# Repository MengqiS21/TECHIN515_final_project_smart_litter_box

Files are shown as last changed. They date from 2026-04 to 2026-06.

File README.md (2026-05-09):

# Smart Cat Litter Box — TECHIN 515 Final Project

An IoT-enabled smart litter box that uses a load cell weight sensor to monitor cat usage patterns and track cat weight over time. The system is built around a Seeed Studio XIAO ESP32-S3 microcontroller and an HX711 24-bit ADC for high-precision weight measurement.

---

## Hardware Requirements

| Component | Specification |
|---|---|
| Microcontroller | Seeed Studio XIAO ESP32-S3 |
| ADC Module | HX711 24-Bit Load Cell Amplifier |
| Sensor | Load cell (rated for expected weight range) |
| Cable | USB-C (for programming and serial monitor) |
| Enclosure | 3D-printed base (see `Base.stl`) |

---

## Wiring

### HX711 (load cell amplifier)

| HX711 Pin | XIAO ESP32-S3 Pin | GPIO |
|---|---|---|
| DT (Data) | D3 | GPIO 4 |
| SCK (Clock) | D4 | GPIO 5 |
| VCC | 3.3V | — |
| GND | GND | — |

Connect the load cell's four wires to the HX711 module following the color convention printed on the HX711 board (typically: Red=E+, Black=E−, White=A−, Green=A+).

### PIR motion sensor

Typical 3-pin HC-SR501-style PIR module wiring to the XIAO ESP32-S3:

| PIR Pin | XIAO ESP32-S3 Pin | GPIO |
|---|---|---|
| VCC | **3.3V** | — |
| GND | **GND** | — |
| OUT (digital signal) | **D3** | GPIO 4 |

Power the PIR from **3.3 V** so its output levels are safe for the ESP32 GPIO. Use **`INPUT_PULLUP`** (or an external pull-up per your module datasheet) on the signal pin if your sketch expects an active-low/open-drain output.

On the XIAO ESP32-S3, **D3** corresponds to **GPIO 4** — set `PIR_PIN` (or equivalent) in your sketch to **`4`** when using this wiring. The sample `code/PIR_data_capture.ino` may default to another pin; update it to match your board.

**HX711 + PIR on one board:** One GPIO cannot be both HX711 **DT** and PIR **OUT**. If you keep PIR on **D3**, move HX711 **DT** to another free digital pin and update the DT pin in your weight-reading sketch so both peripherals can run together.

---

## Software Requirements

### 1. Arduino IDE
Download and install **Arduino IDE 2.x** from https://www.arduino.cc/en/software

### 2. ESP32-S3 Board Support
1. Open Arduino IDE → **File → Preferences**
2. In *Additional boards manager URLs*, add:
   ```
   https://raw.githubusercontent.com/espressif/arduino-esp32/gh-pages/package_esp32_index.json
   ```
3. Go to **Tools → Board → Boards Manager**, search for `esp32`, and install **esp32 by Espressif Systems** (version 2.x or later)

### 3. Required Library
Install via **Tools → Manage Libraries**:

| Library | Author | Version |
|---|---|---|
| `HX711_ADC` | Olav Kallhovd | Latest |

Search for `HX711_ADC` and click **Install**.

> See `code/libraries.txt` for a machine-readable list of required libraries.

---

## Board Configuration in Arduino IDE

Go to **Tools** and set:

| Setting | Value |
|---|---|
| Board | XIAO_ESP32S3 |
| Port | (select the COM/tty port that appears when you plug in the board) |
| USB CDC On Boot | Enabled |
| Upload Speed | 921600 |

---

## Code Structure

```
code/
├── Read_ESP32S3_NoCalib(1).ino   # Step 1 — Connection test (raw ADC, no calibration)
├── Calibration_ESP32S3.ino       # Step 2 — Sensor calibration, saves value to EEPROM
└── Read_ESP32S3.ino              # Step 3 — Production use with calibration applied
```

> **Important (Arduino IDE requirement):** When you open an `.ino` file that is not inside a folder with the same name, Arduino IDE will prompt you to create a matching folder and move the file. Click **OK** to accept — this is required behavior and does not affect the code.

---

## Running the Code — Step by Step

### Step 1: Verify Circuit Connection (No Calibration)

Use this sketch first to confirm that the load cell and HX711 are wired correctly.

1. Open `Read_ESP32S3_NoCalib(1).ino` in Arduino IDE
2. Select the correct board and port (see Board Configuration above)
3. Click **Upload**
4. Open **Tools → Serial Monitor**, set baud rate to **115200**
5. You should see raw ADC values printing continuously
6. Place a weight on the load cell — the values should change noticeably
7. If values change, wiring is correct. Proceed to Step 2.

**Serial commands:**
- `t` — Tare (zero) the sensor

---

### Step 2: Calibrate the Sensor

Run this sketch once to calculate and save a calibration factor to EEPROM.

1. Open `Calibration_ESP32S3.ino` in Arduino IDE
2. Upload to the XIAO ESP32-S3
3. Open **Serial Monitor** at **115200 baud**
4. Follow the on-screen prompts:
   - Remove all weight from the load cell
   - Send `t` to tare (zero) the sensor
   - Place a **known-weight object** (e.g., 100.0 g) on the load cell
   - Type the exact weight value (e.g., `100.0`) in the Serial Monitor and press Enter
   - When asked, send `y` to save the calibration value to EEPROM
5. Note the printed calibration value — it is also saved automatically to EEPROM address 0

**Serial commands during calibration:**
- `t` — Tare
- `r` — Restart calibration
- `c` — Manually enter and save a new calibration factor

---

### Step 3: Read Actual Weight

After calibration, use this sketch for normal operation.

1. Open `Read_ESP32S3.ino` in Arduino IDE
2. Upload to the XIAO ESP32-S3
3. Open **Serial Monitor** at **115200 baud**
4. The sketch automatically reads the calibration factor from EEPROM and prints the calibration value used
5. Weight readings (in grams, relative to calibration) are printed every **1 second**

**Serial commands:**
- `t` — Tare (re-zero the sensor)

> If weight readings appear as large negative numbers, uncomment `LoadCell.setReverseOutput();` in the sketch (line 36) and re-upload.

---

## Troubleshooting

| Symptom | Likely Cause | Fix |
|---|---|-----|
| Timeout error on startup | Incorrect wiring or wrong GPIO pins | Double-check DT→GPIO4, SCK→GPIO5 |
| No serial output | USB CDC not enabled or wrong port | Enable USB CDC On Boot in board settings |
| Values don't change when weight added | Loose connection or broken load cell | Re-seat all connections |
| Calibration value reads as `nan` or `0` | EEPROM not yet written | Run calibration sketch first |
| Weight reads negative | Load cell wired in reverse | Uncomment `setReverseOutput()` |

---

## Repository Contents

| File | Description |
|---|---|
| `code/Calibration_ESP32S3.ino` | Calibration sketch for ESP32-S3 |
| `code/Read_ESP32S3.ino` | Production weight reading sketch |
| `code/Read_ESP32S3_NoCalib(1).ino` | Connection test sketch (raw ADC) |
| `code/libraries.txt` | Required Arduino libraries |
| `Base.stl` | 3D model of the litter box base |
| `TECHIN515_Budget.pdf` | Project budget breakdown |
| `Prototype1_HX711_Weight_Sensor_Test_Report.pdf` | Milestone 1 test report |
| `Smart_Cat_Litter_Box_Milestone1(3).pptx` | Project presentation slides |

---

## Authors

Xin Luo, Yuna Xiong, Mengqi Shi — Spring 2026

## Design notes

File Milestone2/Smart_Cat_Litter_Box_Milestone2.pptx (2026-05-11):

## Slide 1

MILESTONE 2

TEAM PROJECT

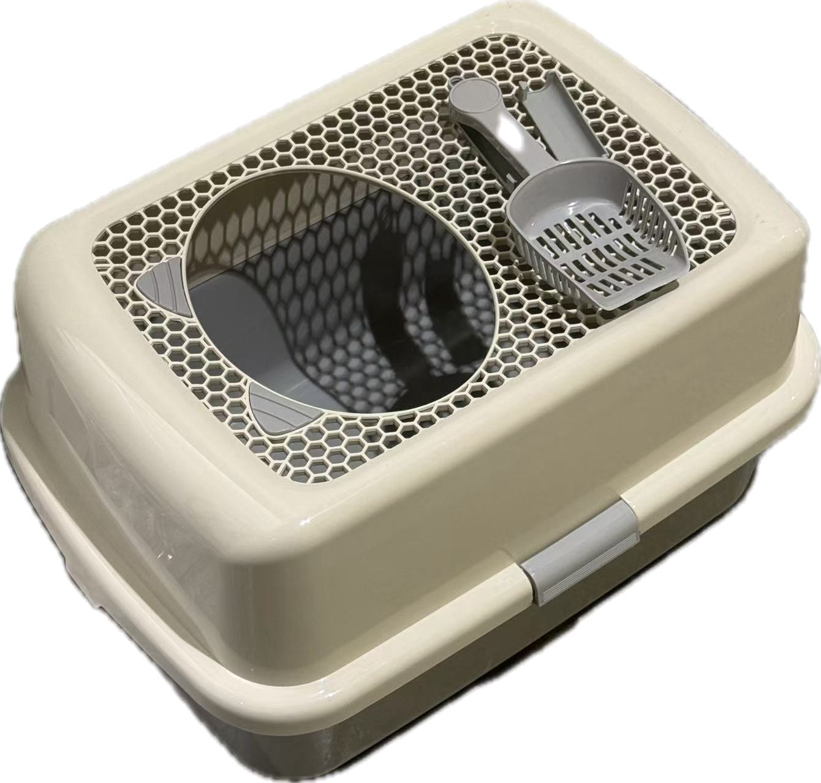
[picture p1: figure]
图片 1

Smart Cat Litter

Box Monitor

Passive health tracking for cats through visit, weight, and pattern monitoring.

TEAM

Mengqi Shi Yuna Xiong Xin Luo

TEAM

Team SmartLitterBox

GITHUB

https://github.com/MengqiS21/TECHIN515_final_project_smart_litter_box

Smart Cat Litter Box Monitor | Milestone 1

1 / 8

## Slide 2

01 PROBLEM

The Problem & Who It Affects

THE PROBLEM

Cat owners have no easy way to detect early signs of health issues from litter box behavior.

BY THE NUMBERS

64.5%

of cats with urinary tract issues show no obvious symptoms until the condition becomes serious

INTENDED USER GROUP

Cats often hide symptoms of illness such as urinary blockages or weight loss. Subtle changes in litter box visit frequency, duration, and body weight are hard to notice without consistent tracking. By the time owners spot a problem, the condition may already be serious.

Cat owners who want passive, automatic monitoring of their cat's health through litter box usage patterns, without relying on manual observation or frequent vet visits.

Smart Cat Litter Box Monitor | Milestone 1

2 / 8

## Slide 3

02 SOLUTION

Our Solution & Key Features

IN ONE SENTENCE

KEY FEATURES

Visit Detection

PIR sensor captures entry and exit automatically for every visit.

A litter box mounted edge device that uses a PIR sensor and load cell to track each visit's duration and weight, runs anomaly detection against a personalized baseline on the ESP32S3, and syncs logs to a cloud dashboard for long term trend viewing.

HARDWARE STACK

XIAO ESP32S3 | Load cell + HX711 | PIR sensor

01

02

Weight Tracking

Load cell measures cat weight per visit and tracks long term trends.

03

On Device Anomaly

Rule based detector compares each visit to a personalized 7 day baseline.

04

Cloud Trends

MQTT upload to a dashboard so owners can view history and alerts.

Smart Cat Litter Box Monitor | Milestone 1

3 / 8

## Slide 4

03 ARCHITECTURE

Updated System Architecture

Proven

In progress

Blocked

NODE A: Sensor Unit

PIR Motion
Sensor

Signal
Processing

Cloud Upload
(MQTT)

ESP32S3
Node A

Frontend
UI

Anomaly
Detection

Cloud
Dashboard

ESP NOW

feedback: updated baseline

NODE B: Weight Unit

Load Cell
+ HX711

ESP32S3
Node B

Two ESP32S3 nodes communicate via ESP NOW. Solid lines mark tested interfaces. Dashed lines mark interfaces not yet verified.

Smart Cat Litter Box Monitor | Milestone 2

4 / 8

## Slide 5

04 TRADE OFF

Trade Off Analysis

Sweeping system parameters to evaluate impact on performance metrics.

Stabilization Window

PARAMETER

HX711 stabilization time controls how long the system waits after detecting a visit before recording a stable weight reading. Tested at 1s, 3s, 5s, and 7s windows to evaluate the trade off between reading accuracy and response speed.

RESULT

At 1s, readings showed high variance due to the cat's movement on the load cell. At 3s, standard deviation dropped significantly but occasional spikes remained. At 5s, mean error reached 0.11 g with 0.23 g standard deviation, providing stable readings with acceptable latency. At 7s, accuracy improved only marginally while adding unnecessary delay.

Communication Protocol

PARAMETER

Evaluated three options for communication between the sensor node (ESP32S3 + PIR) and the weight node (ESP32S3 + HX711): ESP NOW, Wi Fi, and BLE. Compared on latency, power consumption, and ease of implementation.

RESULT

Wi Fi offers high throughput but requires a router and draws significantly more power, which is not ideal for a battery powered device. BLE is low power but introduces pairing complexity and higher latency for real time data transfer. ESP NOW enables direct peer to peer communication between two ESP32S3 boards with no router dependency, sub 10 ms latency, and minimal power overhead.

01

02

Smart Cat Litter Box Monitor | Milestone 2

5 / 8

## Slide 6

05 VALIDATION

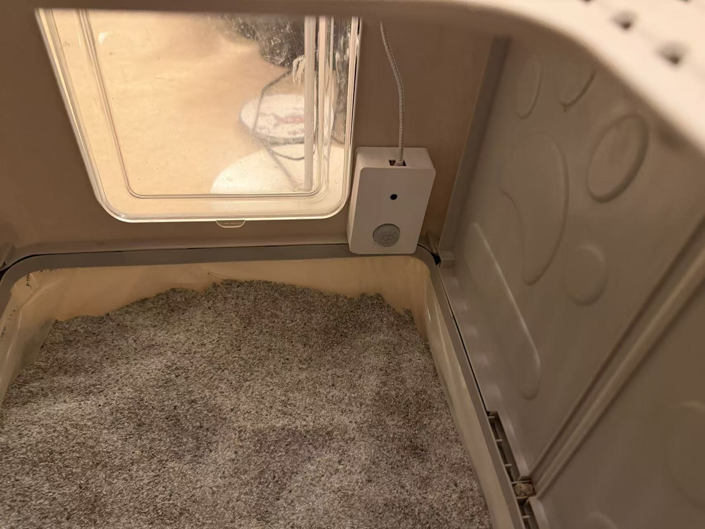
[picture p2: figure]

Validation: Data Collection & Integration

Systematic validation of sensor integration, data pipeline, and model readiness.

Data Labeling

Collected images manually labeled into three categories: Cat A, Cat B, and Empty litter box.

Feature Extraction

Image features extracted through the Edge Impulse DSP pipeline for input into the classification model.

Model Training

Classification model trained to identify which cat is visiting

Sensor Data Collection

PIR sensor detects motion and triggers the ESP32S3 camera module to capture an image.

1

▶

2

▶

3

▶

4

Data Collected

600 images total across three categories (Cat A, Cat B, Empty). All captured via PIR triggered camera on the ESP32S3. Insert sample images from each category and a photo of the hardware setup.

Quantitative Results

HX711 weight sensor validated with mean error 0.11 g and std dev 0.23 g over 20 trials. Image classification accuracy 89.8% on test set.

Model / Next Steps

lassification model can distinguish between Cat A, Cat B, and Empty. Next step is integrating the classifier output with weight and visit duration data to build the full anomaly detection pipeline. Cloud upload and dashboard display to follow.

Smart Cat Litter Box Monitor | Milestone 2

6 / 8

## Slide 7

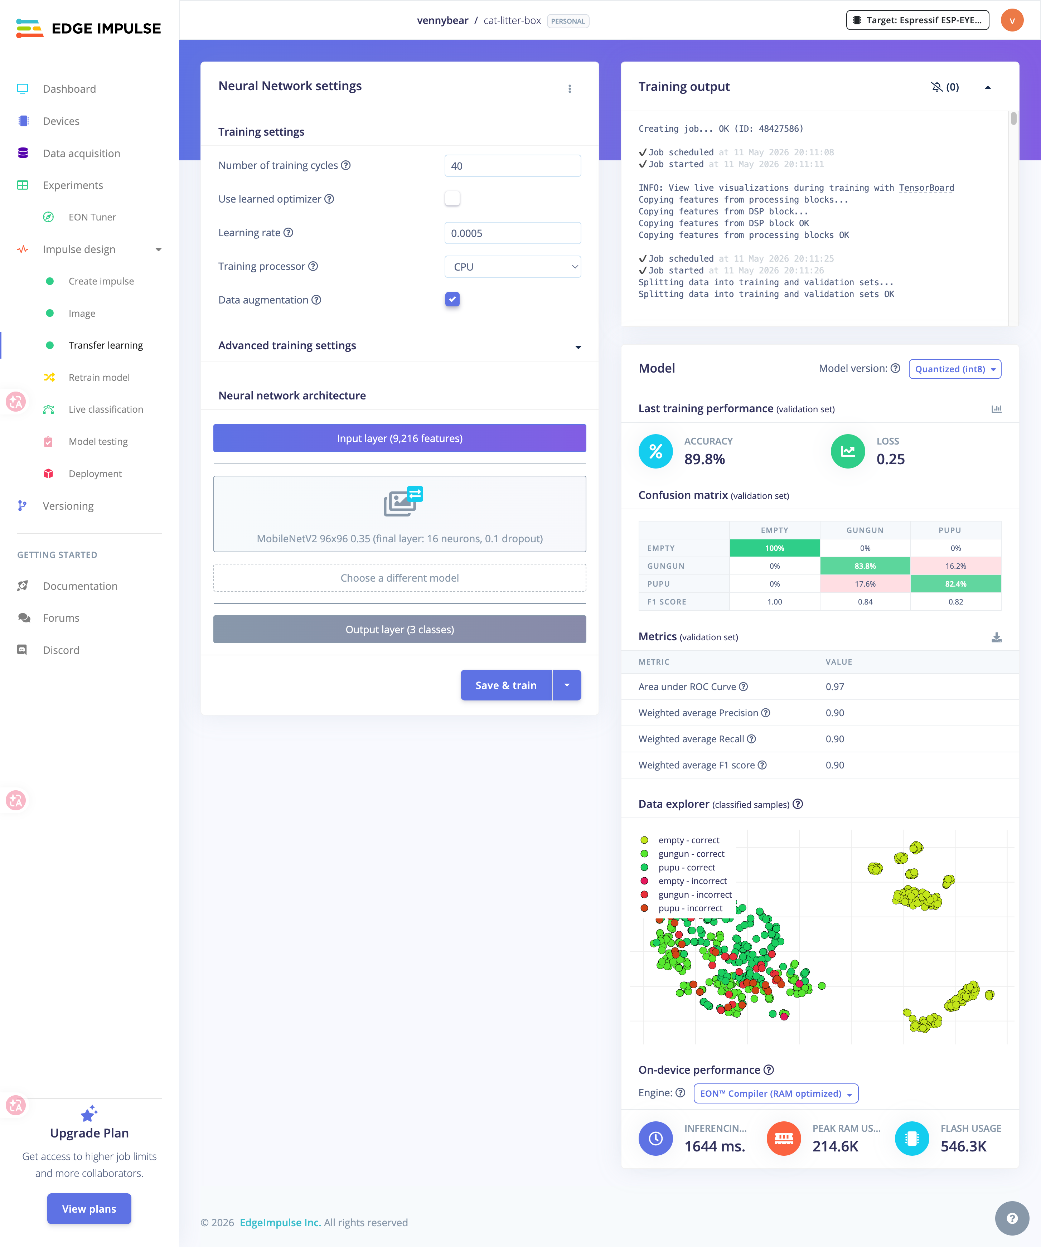
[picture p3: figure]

Smart Cat Litter Box Monitor | Milestone 2

7/ 8

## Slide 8

05 BUDGET

Budget Update

TOTAL BUDGET

$ 350

PURCHASES TO DATE

SPENT SO FAR

$ 57.38

REMAINING

$ 292.62

Item | Qty | Unit Cost | Total
[LiPo battery] | [1] | [$ 5.83] | [$ 5.83]
[LiPo charger module (TP4057, 5pcs)] | [1] | [$ 7.56] | [$ 7.56]
[Cat litter box(Smart Paws,enclosed)] | [1] | [$ 43.99] | [$ 43.99]
[XIAO ESP32S3] | [2] | [$ 0.00] | [$ 0.00]
[Load cell + HX711] | [1] | [$ 0.00] | [$ 0.00]
[PIR motion sensor] | [1] | [$ 0.00] | [$ 0.00]

Smart Cat Litter Box Monitor | Milestone 1

8 / 8

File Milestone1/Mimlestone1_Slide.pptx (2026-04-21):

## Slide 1

MILESTONE 1

TEAM PROJECT

图片 1

Smart Cat Litter

Box Monitor

Passive health tracking for cats through visit, weight, and pattern monitoring.

TEAM

Mengqi Shi Yuna Xiong Xin Luo

TEAM

Team SmartLitterBox

GITHUB

https://github.com/MengqiS21/TECHIN515_final_project_smart_litter_box

Smart Cat Litter Box Monitor | Milestone 1

1 / 6

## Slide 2

01 PROBLEM

The Problem & Who It Affects

THE PROBLEM

Cat owners have no easy way to detect early signs of health issues from litter box behavior.

BY THE NUMBERS

64.5%

of cats with urinary tract issues show no obvious symptoms until the condition becomes serious

INTENDED USER GROUP

Cats often hide symptoms of illness such as urinary blockages or weight loss. Subtle changes in litter box visit frequency, duration, and body weight are hard to notice without consistent tracking. By the time owners spot a problem, the condition may already be serious.

Cat owners who want passive, automatic monitoring of their cat's health through litter box usage patterns, without relying on manual observation or frequent vet visits.

Smart Cat Litter Box Monitor | Milestone 1

2 / 6

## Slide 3

02 SOLUTION

Our Solution & Key Features

IN ONE SENTENCE

KEY FEATURES

Visit Detection

PIR sensor captures entry and exit automatically for every visit.

A litter box mounted edge device that uses a PIR sensor and load cell to track each visit's duration and weight, runs anomaly detection against a personalized baseline on the ESP32S3, and syncs logs to a cloud dashboard for long term trend viewing.

HARDWARE STACK

XIAO ESP32S3 | Load cell + HX711 | PIR sensor

01

02

Weight Tracking

Load cell measures cat weight per visit and tracks long term trends.

03

On Device Anomaly

Rule based detector compares each visit to a personalized 7 day baseline.

04

Cloud Trends

MQTT upload to a dashboard so owners can view history and alerts.

Smart Cat Litter Box Monitor | Milestone 1

3 / 6

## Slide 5

03 ARCHITECTURE

Updated System Architecture

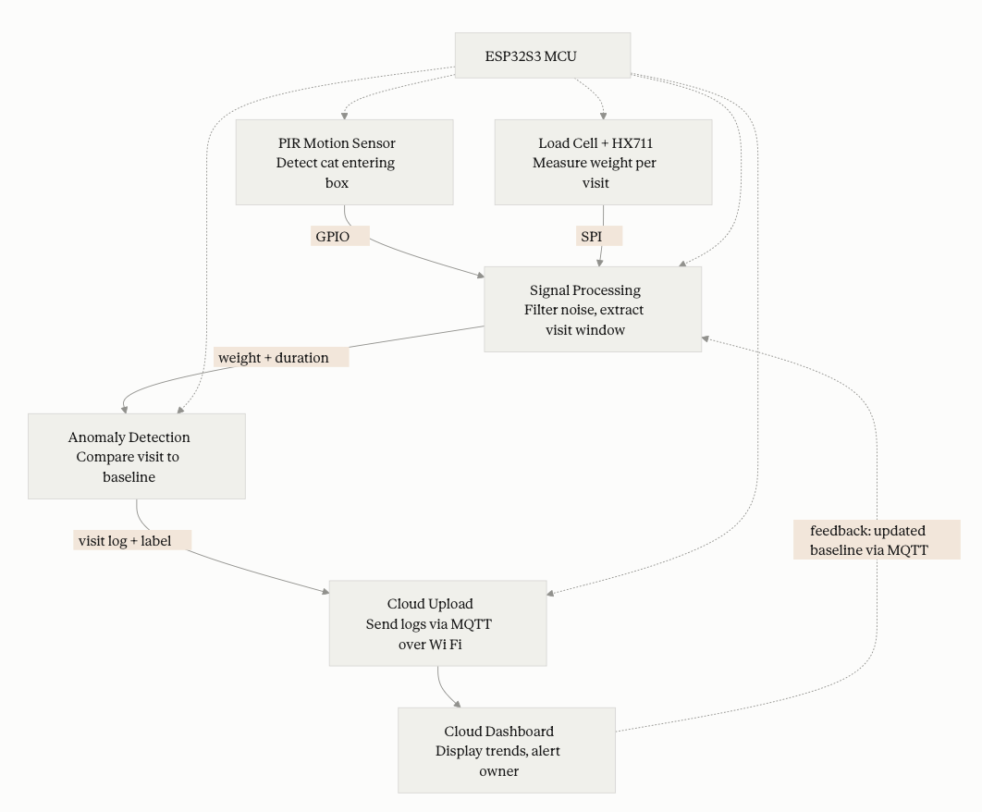
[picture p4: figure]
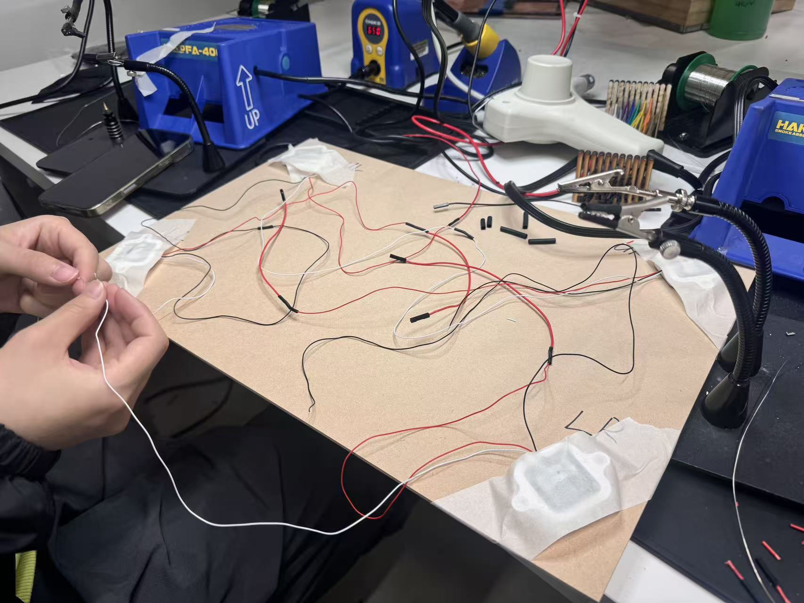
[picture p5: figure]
图片 1
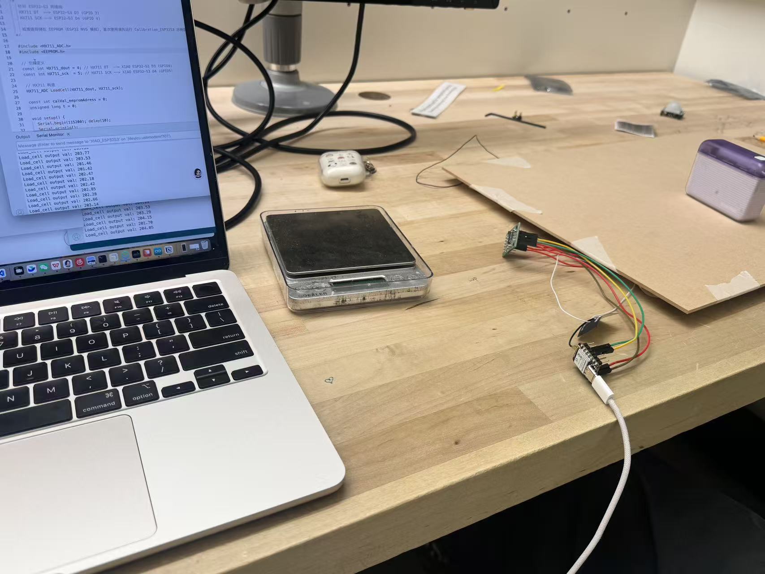
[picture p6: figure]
图片 2

Solid lines mark tested interfaces. Dashed lines mark interfaces not yet verified. Update block status as components move from in progress to proven.

Smart Cat Litter Box Monitor | Milestone 1

4 / 6

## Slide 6

04 VALIDATION

Component Validation & Results

Each component validated with a quantitative test. Evidence: photos, plots, and commits.

YUNA XIONG

Sensor Hardware

METHOD

Connected the HX711 load cell to the XIAO ESP32S3 and placed a 201.56 g reference weight 20 times. Each reading was recorded after a 5000 ms stabilization window at 1000 ms intervals.

RESULT

Mean error 0.11 g, standard deviation 0.23 g. GO verdict, well within the 10 g accuracy threshold.

MENGQI SHI

Signal Stability

METHOD

Analyzed the 20 trial weight readings from the HX711 sensor to evaluate signal noise and reading consistency. Computed error distribution, peak to peak range, and standard deviation across all trials.

RESULT

Peak to peak error range 0.72 g, max error 0.43 g, min error 0.29 g. Signal stable enough to serve as input for the anomaly detection pipeline.

XIN LUO

Data Logging and Transmission

METHOD

Developed the ESP32S3 firmware (Read_ESP32S3.ino) to read and log weight data via serial output. Verified that all 20 readings were captured without data loss at 1000 ms intervals over the test session.

RESULT

20 out of 20 readings successfully captured with zero dropped samples. Firmware logging validated for future MQTT cloud upload integration.

01

02

03

Smart Cat Litter Box Monitor | Milestone 1

5 / 6

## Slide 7

05 BUDGET

Budget Update

TOTAL BUDGET

$ 350

PURCHASES TO DATE

SPENT SO FAR

$ 57.38

REMAINING

$ 292.62

Item | Qty | Unit Cost | Total
[LiPo battery] | [1] | [$ 5.83] | [$ 5.83]
[LiPo charger module (TP4057, 5pcs)] | [1] | [$ 7.56] | [$ 7.56]
[Cat litter box(Smart Paws,enclosed)] | [1] | [$ 43.99] | [$ 43.99]
[XIAO ESP32S3] | [2] | [$ 0.00] | [$ 0.00]
[Load cell + HX711] | [1] | [$ 0.00] | [$ 0.00]
[PIR motion sensor] | [1] | [$ 0.00] | [$ 0.00]

Smart Cat Litter Box Monitor | Milestone 1

6 / 6

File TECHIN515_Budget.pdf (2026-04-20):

## Smart Cat Litter Box Monitor — Team Budget

TECHIN 515 Spring 2026 · Mengqi Shi | Yuna Xiong | Xin Luo · Team Budget: $350.00 · Updated 2026-04-19

### Hardware

Item | Spec / Source | Qty | Unit ($) | Total ($) | Status
XIAO ESP32S3 | Maker Space | 2 | — | 0.00 | MAKER SPACE
Load cell, 4-bar | Maker Space | 1 | — | 0.00 | MAKER SPACE
HX711 amplifier module | Maker Space | 1 | — | 0.00 | MAKER SPACE
PIR motion sensor | Maker Space | 1 | — | 0.00 | MAKER SPACE
LiPo battery, 3.7 V 500 mAh | Jameco / Amazon | 1 | 5.83 | 5.83 | PURCHASED
LiPo charger module (TP4057, 5pcs) | HiLetgo / Amazon | 1 pk | 7.56 | 7.56 | PURCHASED
Resistors / capacitors / headers | Maker Space | — | — | 0.00 | MAKER SPACE
Jumper wires & breadboard | Maker Space | 1 set | — | 0.00 | MAKER SPACE
Cat litter box (Smart Paws, enclosed) | Amazon | 1 | 43.99 | 43.99 | PURCHASED

### PCB & Fabrication

### Cloud & Software

Item | Details | Cost ($)
MQTT broker (HiveMQ Cloud) | Free tier — up to 10 connections | 0.00
Edge Impulse | Free tier | 0.00
Estimated Total Spend | $57.38
Team Budget | $350.00
Remaining (contingency) | $292.62

* ESP32S3, load cell, HX711, PIR, jumper wires, resistors/caps sourced from Maker Space at no cost. PCB fabrication sponsored by school. Purchased Apr 17: LiPo battery $5.83, TP4057 charger 5-pack $7.56, cat litter box $43.99. Remaining $292.62 reserved for high-fidelity enclosure fabrication and any additional components.

2026/4/19 14:25 | TECHIN 515 — Budget
file:///Users/yuna/Desktop/515 Lab2/group project/CFO/budget.html | 1/2

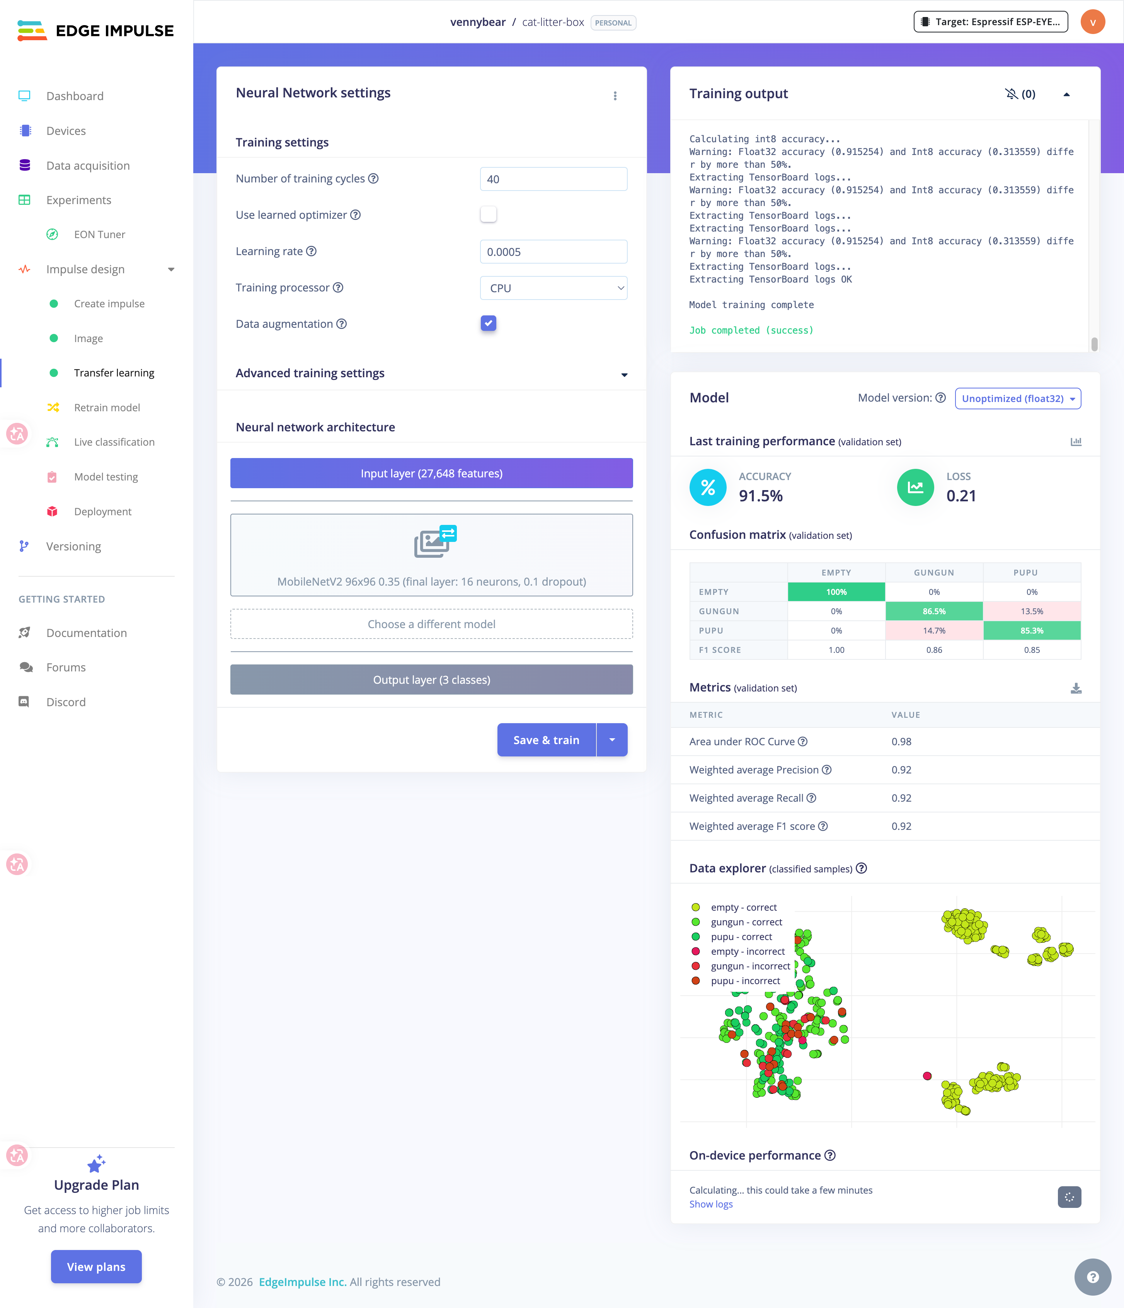
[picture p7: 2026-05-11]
ML screenshot/2round-RGB/Float32 accuracy.png

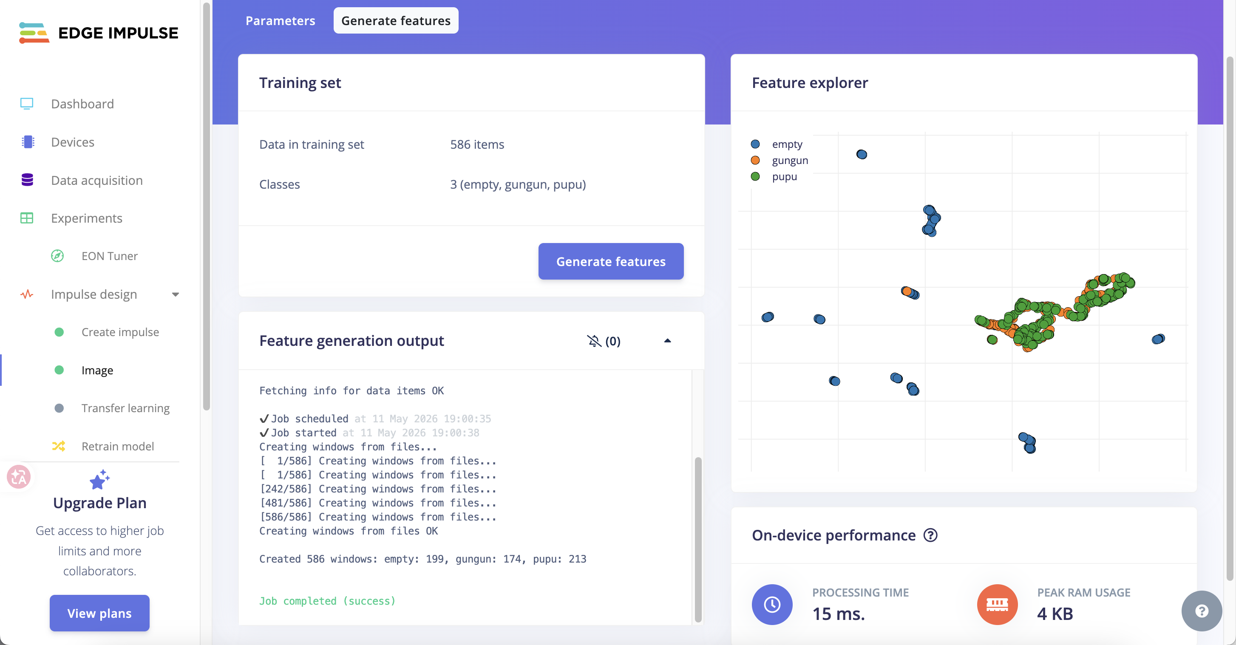
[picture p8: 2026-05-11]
ML screenshot/1-img feature.png

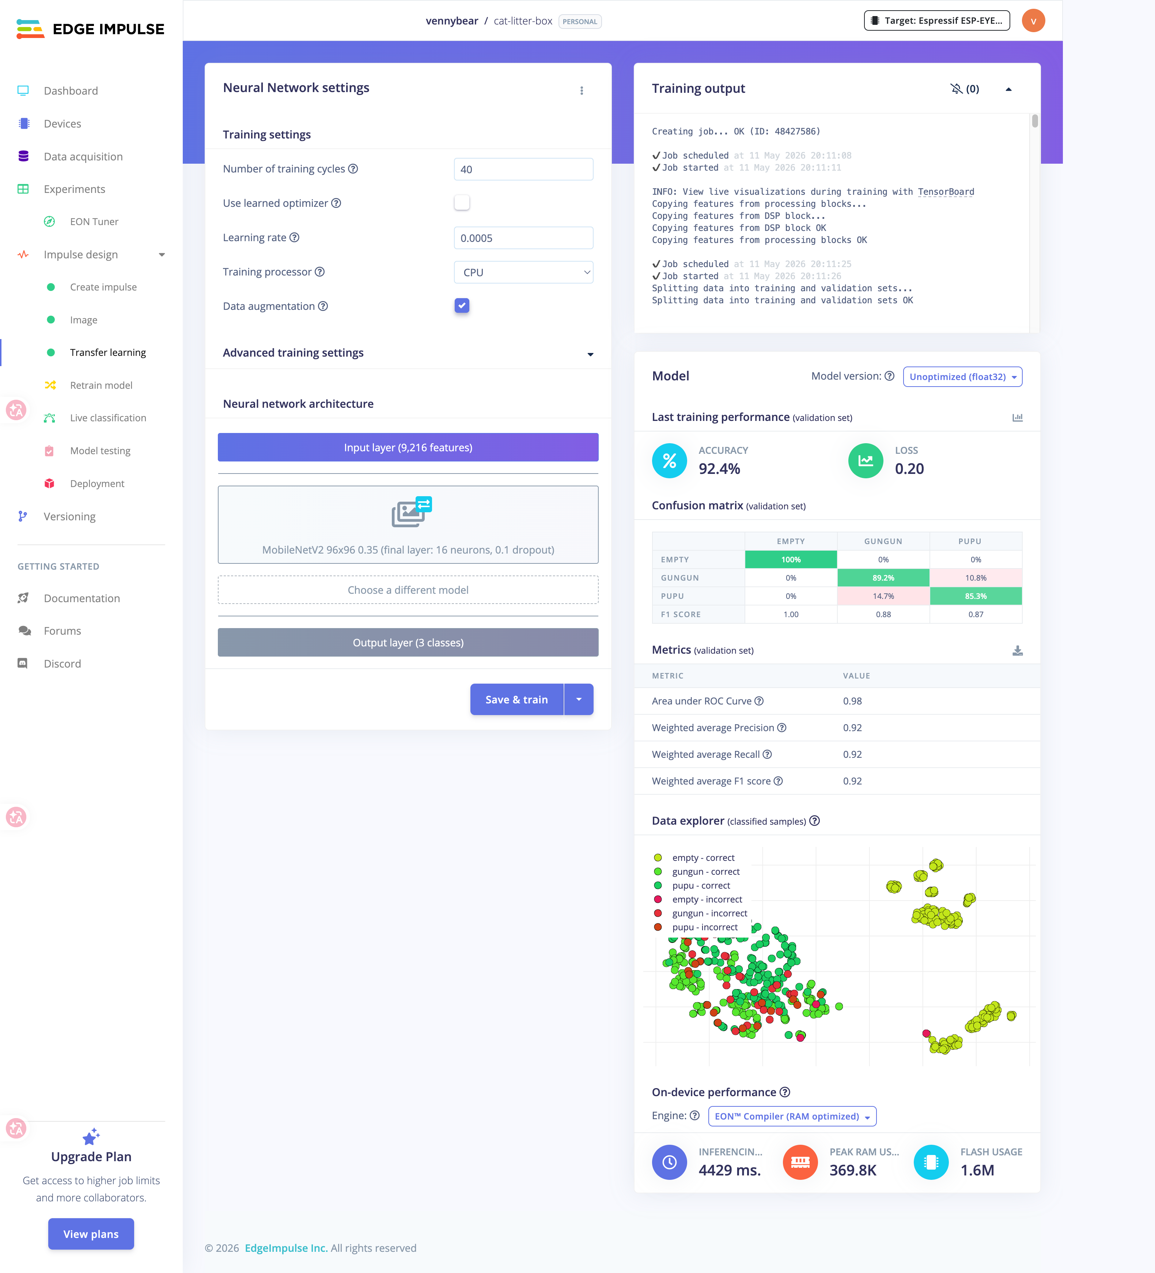
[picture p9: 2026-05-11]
ML screenshot/round3-grayscale/float32.png

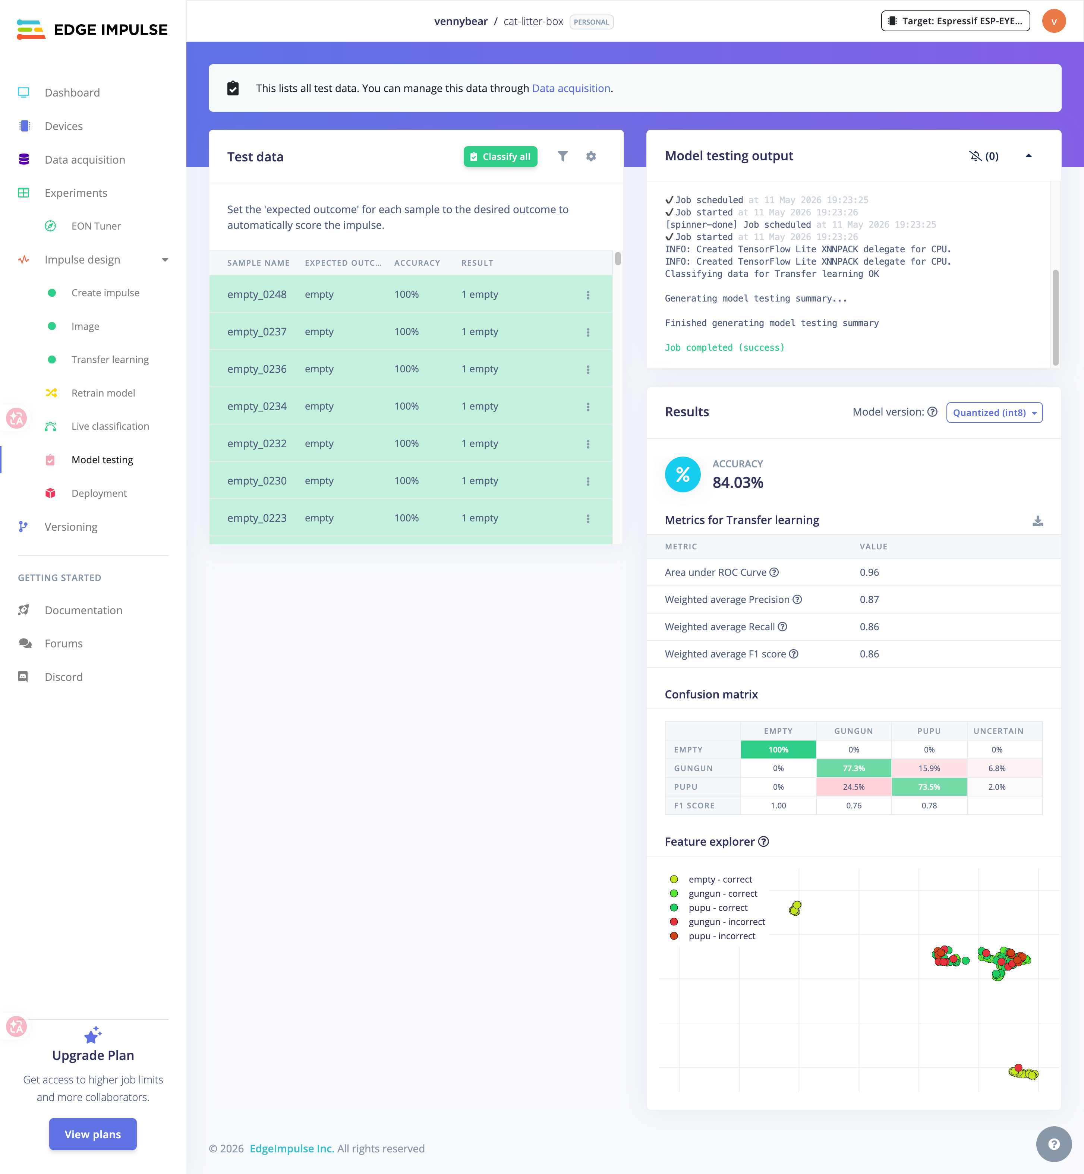
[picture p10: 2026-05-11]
ML screenshot/5-accuracy int8.png

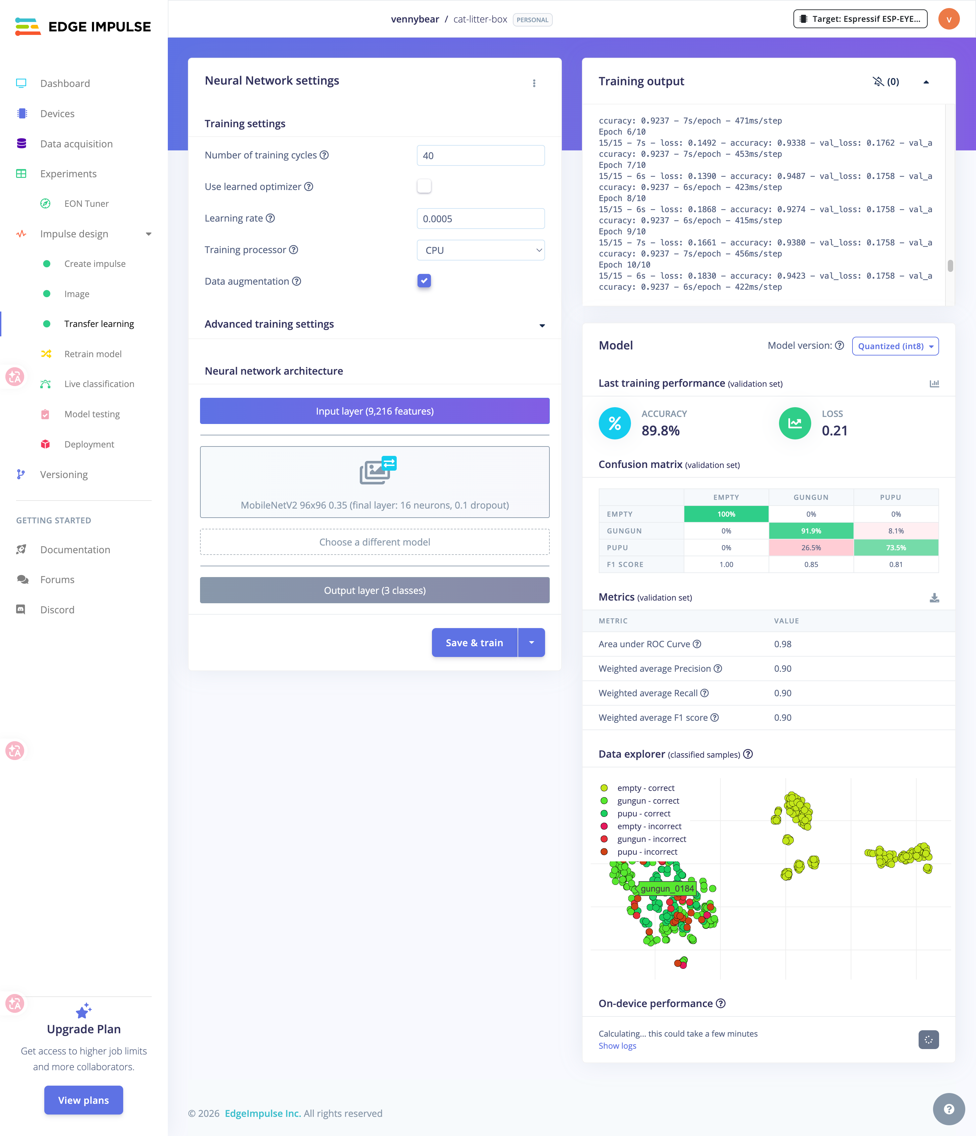
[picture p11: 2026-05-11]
ML screenshot/3-int8.png

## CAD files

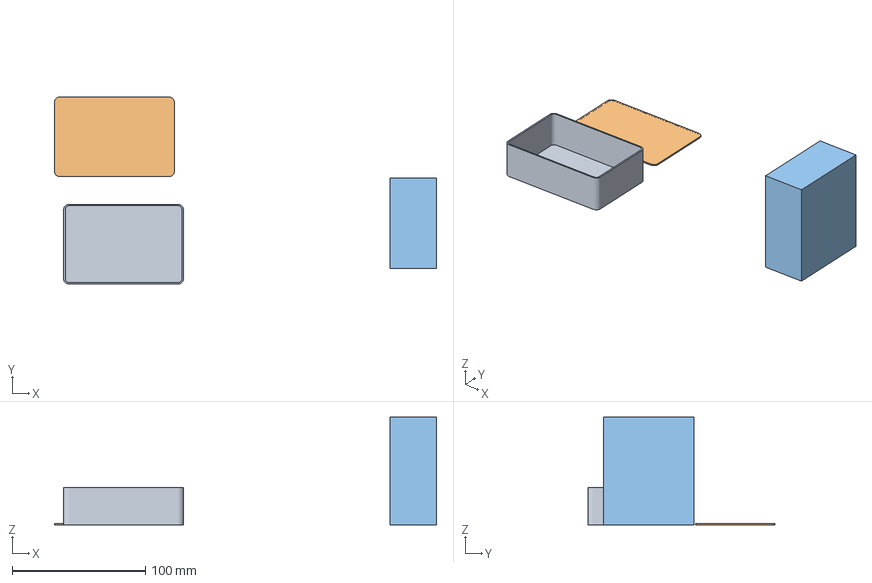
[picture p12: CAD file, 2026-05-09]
enclosure_design/simple_box_generator(1).3mf
287.0 x 140.7 x 81.0 mm
simple_box_generator.stl
simple_box_generator.stl_B

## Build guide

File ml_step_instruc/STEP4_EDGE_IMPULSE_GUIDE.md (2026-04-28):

# Step 4: Edge Impulse 模型训练完整指南
## 用 Edge Impulse 训练猫咪识别模型并部署到 ESP32S3 Sense

---

## 前提条件

在开始之前，你需要：
- 完成 Step 2-3，SD 卡里有标注好的两个文件夹：`cat_a/`（150+ 张）和 `cat_b/`（150+ 张）
- 一台能上网的电脑
- 一个 Edge Impulse 免费账号

---

## Part 1：注册 Edge Impulse 并创建项目

1. 打开 https://studio.edgeimpulse.com/
2. 点击 **Sign up**，用邮箱注册一个免费账号（用学校邮箱 .edu 也可以）
3. 登录后，点击右上角 **Create new project**
4. 项目名称填：`Cat-Identifier-LitterBox`（或任意你喜欢的名字）
5. 选择 **Images** 作为项目类型
6. 点击 **Create**

---

## Part 2：上传照片数据

1. 进入项目后，点击左侧菜单栏的 **Data acquisition**
2. 点击上方的 **Add data** → **Upload data**
3. 上传方式选择 **Select a folder**

### 上传 Cat A 的照片：
- 选择你电脑上的 `cat_a/` 文件夹
- **Label** 填：`cat_a`
- **Upload into category** 选：**Automatically split between training and testing**（Edge Impulse 会自动按 80/20 分成训练集和测试集）
- 点击 **Upload**，等待所有照片上传完成

### 上传 Cat B 的照片：
- 重复上面的步骤，选择 `cat_b/` 文件夹
- **Label** 填：`cat_b`
- 同样选 **Automatically split**
- 点击 **Upload**

### 检查数据：
- 上传完成后，在 **Data acquisition** 页面可以看到所有样本
- 点击顶部的 **Training data** 和 **Test data** 标签切换查看
- 确认两个类别的数量大致平衡（差距不超过 2:1）
- 随机点开几张确认标签正确、照片清晰

---

## Part 3：设计 Impulse（数据处理 Pipeline）

这一步是定义数据从输入到输出的流程。

1. 点击左侧菜单的 **Create impulse**（也叫 Impulse design）
2. 你会看到一个 pipeline 配置界面，按以下方式设置：

### Image data（输入块）：
- **Image width**: `96`
- **Image height**: `96`
- **Resize mode**: `Fit shortest axis`（保持比例缩放后裁剪为正方形）

### 添加 Processing block：
- 点击 **Add a processing block**
- 选择 **Image**（这个块会把原始图片转成模型需要的格式）

### 添加 Learning block：
- 点击 **Add a learning block**
- 选择 **Transfer Learning (Images)**（这就是 MobileNetV2 方案）
- 注意：不要选 "Classification" 里的普通 NN，Transfer Learning 效果好得多

3. 点击 **Save Impulse**

---

## Part 4：配置图像处理参数

1. 点击左侧菜单的 **Image**（在 Impulse design 下面）
2. **Color depth** 选择：**RGB**（猫的毛色是重要特征，保留颜色信息）
3. 点击 **Save parameters**
4. 点击 **Generate features**

这一步会处理你所有的训练图片，生成特征向量。处理完后你会看到一个 2D 可视化图（Feature explorer），如果两只猫的数据点在图上能明显分开，说明数据质量很好，模型训练效果会不错。

---

## Part 5：训练模型

1. 点击左侧菜单的 **Transfer Learning**（在 Image 下面）
2. 配置训练参数：

| 参数 | 推荐值 | 说明 |
|---|---|---|
| Number of training cycles | `50` | 先用 50 个 epoch，如果效果不好再加到 100 |
| Learning rate | `0.0005` | 默认值，通常不需要改 |
| Minimum confidence rating | `0.6` | 低于 60% 置信度的预测视为"不确定" |
| Data augmentation | **开启** | 自动翻转、旋转、亮度调节，增加数据多样性 |

3. 在 **Neural network architecture** 部分：
   - 选择 **MobileNetV2 96x96 0.1**（最小的 MobileNetV2 变体）
   - 这个模型针对 96×96 输入优化，专为资源受限的 MCU 设计
   - 如果看不到这个选项，选择 **MobileNetV2 96x96 0.05** 也行

4. 点击 **Start training**
5. 等待训练完成（通常 5-15 分钟）

### 查看训练结果：
- **Accuracy**（准确率）：目标 > 90%，如果 > 85% 也可以接受
- **Loss**（损失）：越小越好
- **Confusion matrix**（混淆矩阵）：看 cat_a 和 cat_b 分别有多少被正确分类
  - 对角线数字越高越好（正确分类）
  - 非对角线数字越低越好（错误分类）

### 如果准确率低于 85%，尝试：
- 增加训练数据（每只猫加到 200-300 张）
- 开启数据增强（Data augmentation）
- 增加 training cycles 到 100
- 检查数据质量：删掉模糊的、猫不在画面中的、光线太暗的照片

---

## Part 6：测试模型

1. 点击左侧菜单的 **Model testing**
2. 点击 **Classify all**
3. Edge Impulse 会用之前自动分出来的测试集验证模型
4. 查看测试准确率，这个数字比训练准确率更可靠（因为模型没见过测试集的数据）
5. 测试准确率 > 85% 就可以进入部署

---

## Part 7：导出 Arduino Library

1. 点击左侧菜单的 **Deployment**
2. 在搜索框搜索 **Arduino library**
3. 选择 **Arduino library**
4. 下方的优化选项：
   - **Quantized (int8)**: 选择这个！模型更小、推理更快，适合 ESP32
   - 不要选 Float32，那个太大了
5. 点击 **Build**
6. 等待构建完成，浏览器会自动下载一个 `.zip` 文件
   - 文件名类似：`ei-cat-identifier-litterbox-arduino-1.0.1.zip`
   - 不要解压这个文件！

---

## Part 8：在 Arduino IDE 中安装库并运行

### 安装库：
1. 打开 Arduino IDE
2. 点击 **Sketch → Include Library → Add .ZIP Library...**
3. 选择刚才下载的 `.zip` 文件
4. 等待安装完成，底部状态栏会显示 "Library added to your libraries"

### 运行示例测试：
1. 点击 **File → Examples → 你的项目名 - Edge Impulse → esp32 → esp32_camera**
   - 如果找不到，试试重启 Arduino IDE
2. 这个示例代码会用 ESP32S3 的摄像头实时拍照并推理
3. 确认代码中的摄像头引脚定义和你的 XIAO ESP32S3 Sense 一致：
   ```
   #define CAMERA_MODEL_XIAO_ESP32S3
   ```
4. Board 设置：
   - Board: **XIAO_ESP32S3**
   - PSRAM: **OPI PSRAM**（必须开启！）
5. 上传到板子
6. 打开 Serial Monitor（115200 baud）
7. 你应该能看到类似输出：
   ```
   Predictions:
     cat_a: 0.92
     cat_b: 0.05
   ```

### 如果示例代码中没有 XIAO ESP32S3 的摄像头定义：
在代码中找到摄像头引脚部分，替换为：
```cpp
#define PWDN_GPIO_NUM     -1
#define RESET_GPIO_NUM    -1
#define XCLK_GPIO_NUM     10
#define SIOD_GPIO_NUM     40
#define SIOC_GPIO_NUM     39
#define Y9_GPIO_NUM       48
#define Y8_GPIO_NUM       11
#define Y7_GPIO_NUM       12
#define Y6_GPIO_NUM       14
#define Y5_GPIO_NUM       16
#define Y4_GPIO_NUM       18
#define Y3_GPIO_NUM       17
#define Y2_GPIO_NUM       15
#define VSYNC_GPIO_NUM    38
#define HREF_GPIO_NUM     47
#define PCLK_GPIO_NUM     13
```

---

## Part 9：查看 On-Device Performance（设备端性能）

在 Edge Impulse 的 Deployment 页面，构建前会显示预估的设备端性能：

| 指标 | 目标值 | 说明 |
|---|---|---|
| Inferencing time | < 500ms | 推理一次所需时间 |
| Peak RAM usage | < 512KB | ESP32S3 的 PSRAM 有 8MB，绰绰有余 |
| Flash usage | < 1MB | 模型大小，ESP32S3 有 8MB Flash |

如果 RAM 超标，回到 Part 5 选更小的模型（0.05 而不是 0.1），或者把输入分辨率降到 48×48。

---

## 常见问题

| 问题 | 解决方法 |
|---|---|
| 上传照片失败 | 检查照片格式是否为 JPG/PNG；单张不超过 5MB |
| Feature explorer 里两类混在一起 | 数据质量不够，两只猫可能长得太像；增加数据量或检查标注是否正确 |
| 训练准确率高但测试准确率低 | 过拟合了；开启数据增强，或减少 training cycles |
| Arduino 编译报错 "out of memory" | 确认 PSRAM 已开启；选择 int8 量化模型 |
| 编译报错 "cam_hal: DMA overflow" | ESP32 Arduino Core 版本问题，尝试安装 2.0.x 版本的 Core |
| 推理结果两个类别都是 ~0.5 | 模型不确定，可能需要更多数据或照片角度不一致 |

---

## 检查清单

- [ ] Edge Impulse 账号创建完成
- [ ] cat_a 和 cat_b 照片上传完成，数量各 150+
- [ ] Impulse 配置完成：96×96 RGB + Transfer Learning
- [ ] 特征生成完成，Feature explorer 显示两类可分
- [ ] 模型训练完成，准确率 > 85%
- [ ] 测试集验证通过
- [ ] Arduino Library 下载并安装到 Arduino IDE
- [ ] 示例代码烧录到 ESP32S3 Sense，Serial Monitor 显示推理结果
- [ ] 推理结果正确（对着对应的猫，置信度 > 0.7）

**全部通过后，你就可以进入 Step 5：把猫咪识别和体重记录整合到一起了！**

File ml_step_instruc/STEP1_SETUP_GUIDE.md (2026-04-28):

# Smart Cat Litter Box Monitor
## Step 1: 摄像头测试 — 环境搭建指南

---

## 你需要的材料

| 材料 | 说明 | 大概价格 |
|---|---|---|
| XIAO ESP32S3 Sense | 带 OV2640 摄像头扩展板 | ~$14 |
| USB-C 数据线 | 连接电脑，确保是**数据线**不是纯充电线 | 你应该有 |
| MicroSD 卡 | 8GB-32GB，**FAT32** 格式化 | ~$5 |
| 电脑 | Windows / macOS / Linux 均可 | — |

---

## Arduino IDE 配置步骤

### 1. 安装 Arduino IDE
- 下载地址：https://www.arduino.cc/en/software
- 推荐 Arduino IDE 2.x 版本

### 2. 添加 ESP32 Board Support
1. 打开 Arduino IDE
2. 进入 **File → Preferences**
3. 在 **Additional Board Manager URLs** 里添加：
   ```
   https://raw.githubusercontent.com/espressif/arduino-esp32/gh-pages/package_esp32_index.json
   ```
4. 点 OK
5. 进入 **Tools → Board → Boards Manager**
6. 搜索 **esp32**
7. 安装 **esp32 by Espressif Systems**（选 3.x 版本）
8. 等待安装完成（需要几分钟）

### 3. 选择 Board 设置
在 **Tools** 菜单中设置：
- **Board**: XIAO_ESP32S3
- **PSRAM**: OPI PSRAM  ⚠️ **必须开启，否则摄像头不工作！**
- **Upload Speed**: 921600
- **Port**: 选择你的 USB 端口（插上板子后会出现）

### 4. 准备 SD 卡
- 用电脑把 MicroSD 卡格式化为 **FAT32**
  - Windows: 右键 → 格式化 → FAT32
  - macOS: 磁盘工具 → 抹掉 → MS-DOS (FAT)
- 插入 XIAO ESP32S3 Sense 扩展板的 SD 卡槽

---

## 烧录和测试

### 1. 打开代码
- 用 Arduino IDE 打开 `camera_test.ino`

### 2. 上传
- 用 USB-C 连接板子和电脑
- 点击 **Upload** (→ 箭头按钮)
- 等待编译和上传完成

### 3. 查看结果
- 打开 **Tools → Serial Monitor**
- 波特率设为 **115200**
- 你应该看到类似输出：
  ```
  =========================================
    Smart Cat Litter Box Monitor
    Step 1: Camera Test
  =========================================

  [Camera] PSRAM found! Using VGA (640x480)
  [Camera] Init OK!
  [SD] Card type: SDHC
  [SD] Card size: 14832 MB
  [SD] Init OK!

  [Ready] All hardware initialized!
  [Ready] Send 'p' in Serial Monitor to take a photo.
  [Ready] Or just wait — auto-captures every 5 seconds.

  --- Taking photo... ---
  [Photo] Captured! Size: 23456 bytes, Resolution: 640x480
  [SD] Saved: /photo_0001.jpg (23456 bytes)
  --- Photo saved successfully! ---
  ```

### 4. 检查照片
- 拔出 SD 卡，插到电脑上
- 你应该能看到 `photo_0001.jpg`, `photo_0002.jpg` 等文件
- 打开确认照片清晰、颜色正常

---

## 常见问题

| 问题 | 解决方法 |
|---|---|
| Camera init FAILED | 检查 PSRAM 是否开启；确认摄像头模块插紧 |
| SD mount FAILED | 确认 SD 卡是 FAT32；确认扩展板连接正确 |
| 照片全黑 | 摄像头镜头上可能有保护膜，撕掉 |
| 照片偏色（偏绿/偏蓝） | 正常，前几帧可能颜色不准，多拍几张自动校准 |
| Serial Monitor 没输出 | 检查波特率是否 115200；按一下板子上的 Reset 按钮 |
| 找不到 USB 端口 | 换一根数据线（很多线只能充电不能传数据） |

---

## 测试成功的标志 ✓

- [ ] Serial Monitor 显示 Camera Init OK
- [ ] Serial Monitor 显示 SD Init OK
- [ ] SD 卡上有 .jpg 文件
- [ ] 照片打开后清晰可见、颜色基本正常

**全部通过后，你就可以进入 Step 2：搭建自动采集环境了！**

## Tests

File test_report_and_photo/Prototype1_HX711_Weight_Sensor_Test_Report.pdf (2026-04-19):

# Prototype 1 — HX711 Weight Sensor Feasibility Test

TECHIN 515 Group Project — Smart Cat Litter Box Monitor

Tester: Yuna Xiong, Xin Luo | Date: 2026-04-19
Hardware: XIAO ESP32-S3 + HX711 + 4-bar load cell | Firmware: Read_ESP32S3.ino (stabilizing 5000ms, interval 1000ms)
Known reference weight: 201.56 g | Test method: Place/remove reference weight 20 times, record each reading

### WEIGHT READING RESULTS (20 TRIALS)

# | Actual Weight (g) | Displayed Weight (g) | Error (g)

1 | 201.56 | 201.80 | +0.24
2 | 201.56 | 201.90 | +0.34
3 | 201.56 | 201.51 | −0.05
4 | 201.56 | 201.75 | +0.19
5 | 201.56 | 201.99 | +0.43
6 | 201.56 | 201.56 | 0.00
7 | 201.56 | 201.27 | −0.29
8 | 201.56 | 201.94 | +0.38
9 | 201.56 | 201.37 | −0.19
10 | 201.56 | 201.66 | +0.10
11 | 201.56 | 201.61 | +0.05
12 | 201.56 | 201.99 | +0.43
13 | 201.56 | 201.80 | +0.24
14 | 201.56 | 201.85 | +0.29
15 | 201.56 | 201.99 | +0.43
16 | 201.56 | 201.46 | −0.10
17 | 201.56 | 201.42 | −0.14
18 | 201.56 | 201.47 | −0.09
19 | 201.56 | 201.44 | −0.12
20 | 201.56 | 201.56 | 0.00

### STATISTICAL SUMMARY

2026/4/19 00:40 | Prototype 1 — HX711 Weight Sensor Test Report

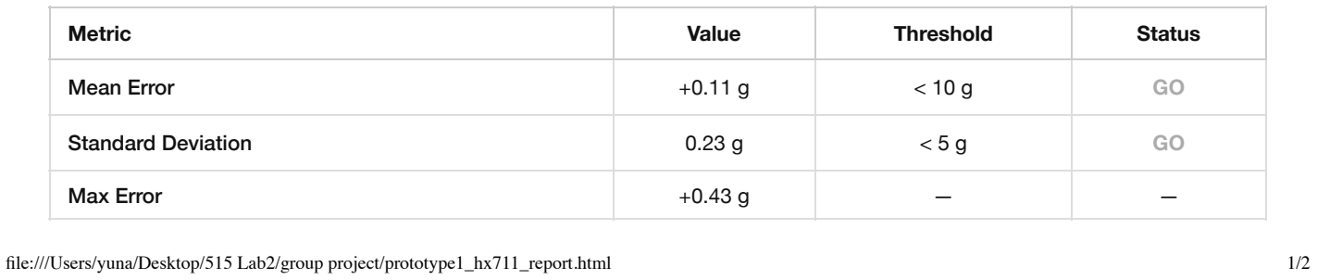
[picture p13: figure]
Metric; Value; Threshold; Status; Mean Error; Standard Deviation; Max Error; file:///Users/yuna/Desktop/515 Lab2/group project/prototype1_hx711_report.html

Metric | Value | Threshold | Status
Min Error | −0.29 g | — | —
Error Range (peak-to-peak) | 0.72 g | — | —

### GO / NO-GO VERDICT — HX711

GO | Mean error 0.11 g — well within 10 g threshold
GO | Std dev 0.23 g — well within 5 g threshold

Conclusion: The HX711 load cell sensor reliably produces stable and accurate weight readings. With a mean error of only 0.11 g and standard deviation of 0.23 g against a 201.56 g reference weight, the sensor exceeds accuracy requirements for cat weight monitoring (target range 3,000–6,000 g). The HX711 component of Prototype 1 is validated. PIR trigger accuracy test to follow upon hardware integration.

2026/4/19 00:40 | Prototype 1 — HX711 Weight Sensor Test Report
file:///Users/yuna/Desktop/515 Lab2/group project/prototype1_hx711_report.html | 2/2

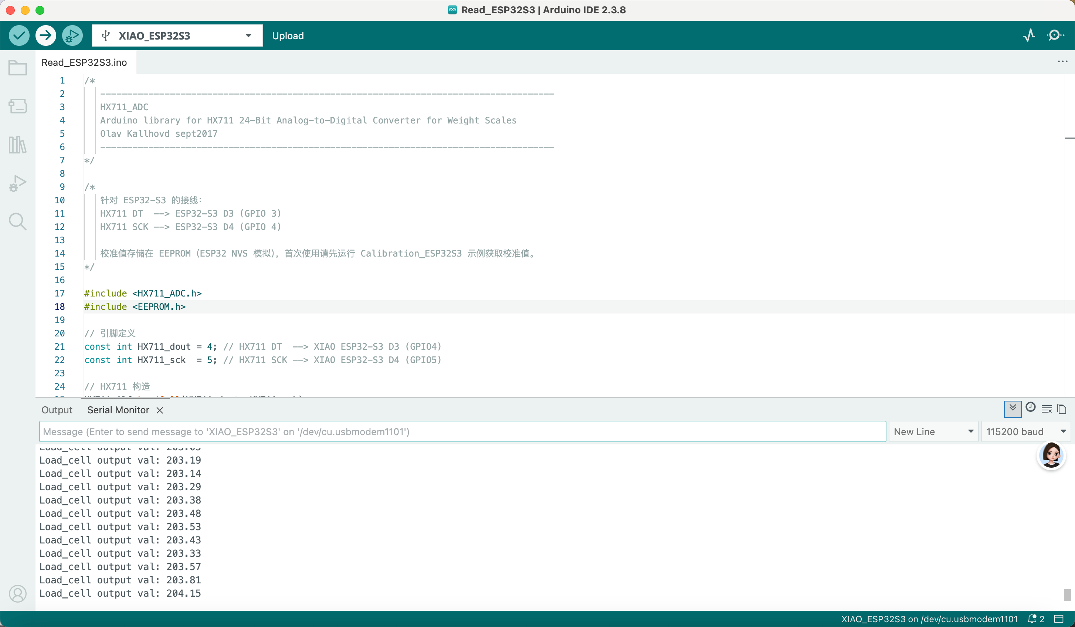
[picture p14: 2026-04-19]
test_report_and_photo/test1.png

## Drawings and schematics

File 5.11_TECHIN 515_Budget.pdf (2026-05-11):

## Smart Cat Litter Box Monitor — Team Budget

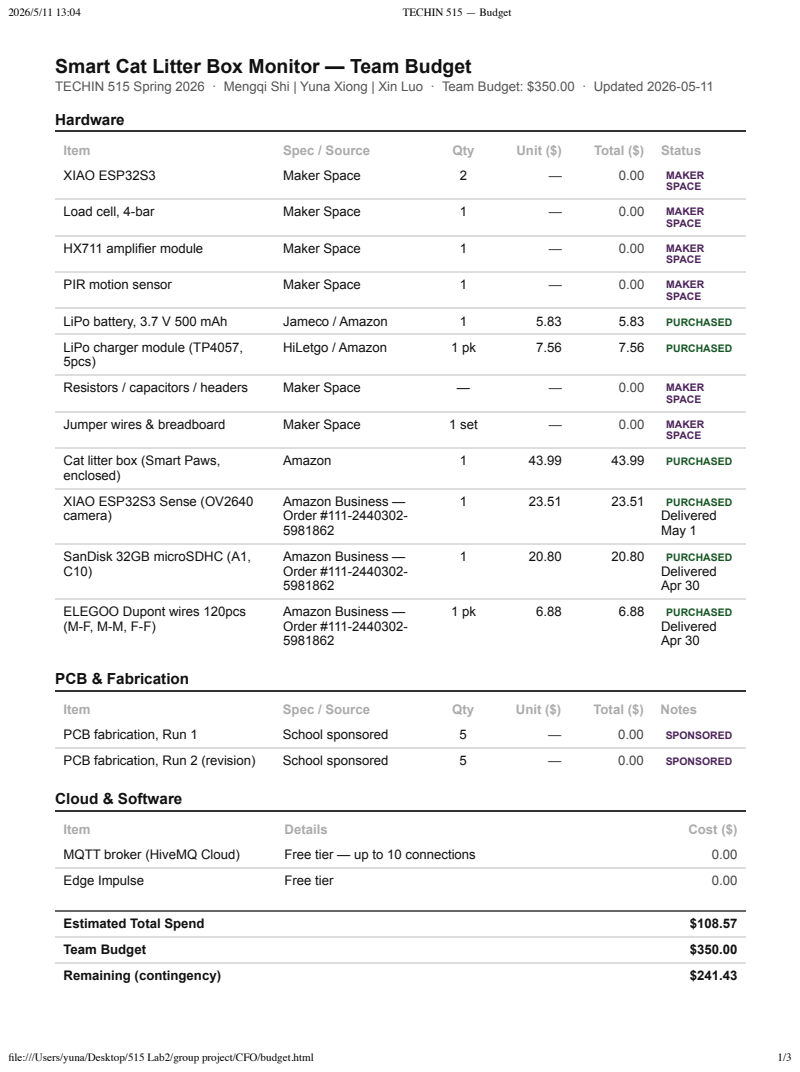
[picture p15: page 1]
Item; Spec / Source; Qty; Unit ($); Total ($); Status; XIAO ESP32S3; Maker Space; MAKER; SPACE; Load cell, 4-bar; HX711 amplifier module; PIR motion sensor; LiPo battery, 3.7 V 500 mAh; Jameco / Amazon; PURCHASED; HiLetgo / Amazon; Resistors / capacitors / headers; Jumper wires & breadboard; 1 set; Amazon; Amazon Business — Order #111-2440302- 5981862; Delivered May 1; SanDisk 32GB microSDHC (A1, C10); Delivered Apr 30; PCB & Fabrication; Notes; PCB fabrication, Run 1; School sponsored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

TECHIN 515 Spring 2026 · Mengqi Shi | Yuna Xiong | Xin Luo · Team Budget: $350.00 · Updated 2026-05-11
Hardware

LiPo charger module (TP4057,
5pcs)

Cat litter box (Smart Paws,
enclosed)
XIAO ESP32S3 Sense (OV2640
camera)

ELEGOO Dupont wires 120pcs

Estimated Total Spend | $108.57
Team Budget | $350.00
Remaining (contingency) | $241.43

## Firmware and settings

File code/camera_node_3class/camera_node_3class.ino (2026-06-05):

/*
 * Smart Cat Litter Box — Camera Node (3-class model)
 * Board : XIAO ESP32S3 Sense  |  PSRAM: OPI PSRAM  |  115200 baud
 *
 * Model labels: "empty", "gungun" (=Wesley), "pupu" (=Pupu)
 * All three classes distinguished by camera; Wesley displays as "Wesley" everywhere.
 */

#include <catIdentifierBig.h>
#include "edge-impulse-sdk/dsp/image/image.hpp"
#include "esp_camera.h"
#include "esp_heap_caps.h"
#include "esp_now.h"
#include <WiFi.h>
#include "esp_wifi.h"

// Override EI weak ei_calloc — must use C++ linkage (not extern "C"); route to PSRAM.
__attribute__((weak)) void* ei_calloc(size_t nitems, size_t size) {
    void* p = heap_caps_calloc(nitems, size, MALLOC_CAP_SPIRAM | MALLOC_CAP_8BIT);
    if (!p) p = heap_caps_calloc(nitems, size, MALLOC_CAP_DEFAULT);
    return p;
}

// ── WiFi ─────────────────────────────────────────────────────
const char* WIFI_SSID = "MengqiPhone";
const char* WIFI_PASS = "gaoxiangshibenben";
// If camera WiFi fails: set this to weight_node serial "[WiFi] Connected! ... Ch=?"
#ifndef WIFI_FALLBACK_CHANNEL
#define WIFI_FALLBACK_CHANNEL 6
#endif

// Returns hotspot channel if seen, else 0.
static int wifiScanForSsid(const char* ssid) {
    int n = WiFi.scanNetworks(false, true);
    Serial.printf("[WiFi] Scan: %d networks", n);
    int ch = 0;
    int bestRssi = -999;
    for (int i = 0; i < n; i++) {
        if (WiFi.SSID(i) == ssid) {
            if (WiFi.RSSI(i) > bestRssi) {
                bestRssi = WiFi.RSSI(i);
                ch = WiFi.channel(i);
            }
            Serial.printf(" | \"%s\" Ch=%d RSSI=%d", ssid, WiFi.channel(i), WiFi.RSSI(i));
        }
    }
    Serial.println(ch ? "" : " | hotspot NOT seen (2.4GHz? hotspot on?)");
    WiFi.scanDelete();
    return ch;
}

static bool wifiConnectStation(const char* ssid, const char* pass, int tries) {
    WiFi.mode(WIFI_STA);
    WiFi.setSleep(false);
    WiFi.disconnect(true);
    delay(100);
    WiFi.begin(ssid, pass);
    Serial.printf("[WiFi] Connecting to \"%s\"", ssid);
    for (int i = 0; i < tries && WiFi.status() != WL_CONNECTED; i++) {
        delay(500);
        Serial.print(".");
    }
    return WiFi.status() == WL_CONNECTED;
}

// ── PIR ──────────────────────────────────────────────────────
#define PIR_PIN          2        // D1 (GPIO2)
#define PIR_COOLDOWN_MS  10000
#define PIR_WARMUP_MS    15000

// ── Camera pins (XIAO ESP32S3 Sense) ─────────────────────────
#define PWDN_GPIO_NUM  -1
#define RESET_GPIO_NUM -1
#define XCLK_GPIO_NUM  10
#define SIOD_GPIO_NUM  40
#define SIOC_GPIO_NUM  39
#define Y9_GPIO_NUM    48
#define Y8_GPIO_NUM    11
#define Y7_GPIO_NUM    12
#define Y6_GPIO_NUM    14
#define Y5_GPIO_NUM    16
#define Y4_GPIO_NUM    18
#define Y3_GPIO_NUM    17
#define Y2_GPIO_NUM    15
#define VSYNC_GPIO_NUM 38
#define HREF_GPIO_NUM  47
#define PCLK_GPIO_NUM  13

#define CAM_COLS 320
#define CAM_ROWS 240

// ── ESP-NOW ───────────────────────────────────────────────────
uint8_t weightNodeMAC[] = {0x1C, 0xDB, 0xD4, 0x5C, 0x8D, 0xEC};
typedef struct { uint8_t cat_id; float confidence; uint32_t timestamp_ms; char method[8]; } CatIDPacket;

// ── Globals ───────────────────────────────────────────────────
static bool          cam_ok       = false;
static int           lastPirState = LOW;
static unsigned long lastTriggerTime = 0;
static int           photoCount   = 0;
uint8_t*             snapshot_buf = nullptr;

// ── EI signal callback ────────────────────────────────────────
static int ei_camera_get_data(size_t offset, size_t length, float* out_ptr) {
    size_t pixel_ix   = offset * 3;
    size_t out_ptr_ix = 0;
    while (out_ptr_ix < length) {
        out_ptr[out_ptr_ix] = (snapshot_buf[pixel_ix + 2] << 16)
                            + (snapshot_buf[pixel_ix + 1] <<  8)
                            +  snapshot_buf[pixel_ix];
        out_ptr_ix++;
        pixel_ix += 3;
    }
    return 0;
}

// ── Camera init ───────────────────────────────────────────────
bool initCamera() {
    camera_config_t cfg;
    cfg.ledc_channel = LEDC_CHANNEL_0; cfg.ledc_timer = LEDC_TIMER_0;
    cfg.pin_d0 = Y2_GPIO_NUM; cfg.pin_d1 = Y3_GPIO_NUM;
    cfg.pin_d2 = Y4_GPIO_NUM; cfg.pin_d3 = Y5_GPIO_NUM;
    cfg.pin_d4 = Y6_GPIO_NUM; cfg.pin_d5 = Y7_GPIO_NUM;
    cfg.pin_d6 = Y8_GPIO_NUM; cfg.pin_d7 = Y9_GPIO_NUM;
    cfg.pin_xclk = XCLK_GPIO_NUM; cfg.pin_pclk = PCLK_GPIO_NUM;
    cfg.pin_vsync = VSYNC_GPIO_NUM; cfg.pin_href = HREF_GPIO_NUM;
    cfg.pin_sccb_sda = SIOD_GPIO_NUM; cfg.pin_sccb_scl = SIOC_GPIO_NUM;
    cfg.pin_pwdn = PWDN_GPIO_NUM; cfg.pin_reset = RESET_GPIO_NUM;
    cfg.xclk_freq_hz = 20000000;
    cfg.pixel_format = PIXFORMAT_JPEG;
    cfg.frame_size   = FRAMESIZE_QVGA;
    cfg.jpeg_quality = 12;
    cfg.fb_count     = 1;
    cfg.fb_location  = CAMERA_FB_IN_PSRAM;
    cfg.grab_mode    = CAMERA_GRAB_WHEN_EMPTY;
    if (esp_camera_init(&cfg) != ESP_OK) { Serial.println("[CAM] Init FAILED"); return false; }
    Serial.println("[CAM] Init OK");
    return true;
}

// ── Capture + resize ──────────────────────────────────────────
bool captureAndResize() {
    camera_fb_t* fb = esp_camera_fb_get();
    if (!fb) { Serial.println("[CAM] Capture FAILED"); return false; }
    bool ok = fmt2rgb888(fb->buf, fb->len, PIXFORMAT_JPEG, snapshot_buf);
    esp_camera_fb_return(fb);
    if (!ok) { Serial.println("[CAM] fmt2rgb888 FAILED"); return false; }
    ei::image::processing::crop_and_interpolate_rgb888(
        snapshot_buf, CAM_COLS, CAM_ROWS,
        snapshot_buf, EI_CLASSIFIER_INPUT_WIDTH, EI_CLASSIFIER_INPUT_HEIGHT);
    return true;
}

// ── Inference ─────────────────────────────────────────────────
// Labels: "empty"=0, "gungun"=Wesley=1, "pupu"=Pupu=2
uint8_t runInference(float* conf_out) {
    *conf_out = 0.0f;

    ei::signal_t signal;
    signal.total_length = EI_CLASSIFIER_INPUT_WIDTH * EI_CLASSIFIER_INPUT_HEIGHT;
    signal.get_data     = &ei_camera_get_data;

    ei_impulse_result_t result = {0};
    EI_IMPULSE_ERROR err = run_classifier(&signal, &result, false);
    if (err != EI_IMPULSE_OK) {
        Serial.printf("[EI] Classifier error %d\n", err);
        return 0;
    }

    float best = 0; int bi = 0;
    for (size_t i = 0; i < EI_CLASSIFIER_LABEL_COUNT; i++) {
        if (result.classification[i].value > best) {
            best = result.classification[i].value; bi = i;
        }
    }
    *conf_out = best;
    const char* label = result.classification[bi].label;
    // Display "Wesley" for gungun label
    const char* display = (strcasecmp(label, "gungun") == 0) ? "Wesley" : label;
    Serial.printf("[EI] label=%s conf=%.2f\n", display, best);

    if (best <= 0.7f)                          return 0;  // low confidence → weight fallback
    if (strcasecmp(label, "gungun") == 0)      return 1;  // Wesley
    if (strcasecmp(label, "pupu")   == 0)      return 2;  // Pupu
    return 0;                                              // empty → weight fallback
}

// ── ESP-NOW ───────────────────────────────────────────────────

void sendCatID(uint8_t cat_id, float conf) {
    CatIDPacket pkt;
    pkt.cat_id = cat_id; pkt.confidence = conf;
    pkt.timestamp_ms = millis();
    strncpy(pkt.method, "CAM", sizeof(pkt.method));
    esp_now_send(weightNodeMAC, (uint8_t*)&pkt, sizeof(pkt));
    const char* names[] = {"Unknown", "Wesley", "Pupu"};
    Serial.printf("[CAM] Sent cat=%s conf=%.2f\n", names[cat_id], conf);
}

// ── Setup ─────────────────────────────────────────────────────
void setup() {
    Serial.begin(115200);
    delay(300);
    Serial.println("=== Camera Node (3-class) ===");

    if (!psramFound()) Serial.println("[WARN] PSRAM not found! Set Tools→PSRAM→OPI PSRAM");

    pinMode(PIR_PIN, INPUT);
    lastPirState = digitalRead(PIR_PIN);
    Serial.printf("[PIR] Warming up %d s...\n", PIR_WARMUP_MS / 1000);
    delay(PIR_WARMUP_MS);
    lastPirState = digitalRead(PIR_PIN);
    Serial.println("[PIR] Ready");

    // WiFi: sync ESP-NOW channel with weight_node (not for MQTT). Both must use same Ch.
    const int wifiTries = 60;  // 30 s
    bool wifiOk = wifiConnectStation(WIFI_SSID, WIFI_PASS, wifiTries);
    if (!wifiOk) {
        Serial.println("\n[WiFi] Retry once...");
        wifiOk = wifiConnectStation(WIFI_SSID, WIFI_PASS, wifiTries);
    }
    if (wifiOk) {
        Serial.printf("\n[WiFi] OK  IP=%s  Ch=%d  (weight must show same Ch)\n",
                      WiFi.localIP().toString().c_str(), WiFi.channel());
    } else {
        wl_status_t st = WiFi.status();
        Serial.printf("\n[WiFi] FAILED (status=%d", (int)st);
        if (st == WL_NO_SSID_AVAIL) Serial.print(", NO_SSID");
        else if (st == WL_CONNECT_FAILED) Serial.print(", AUTH_FAIL");
        else if (st == WL_DISCONNECTED) Serial.print(", DISCONNECTED");
        Serial.println(")");
        int scanCh = wifiScanForSsid(WIFI_SSID);
        int fallbackCh = scanCh ? scanCh : WIFI_FALLBACK_CHANNEL;
        esp_wifi_set_channel(fallbackCh, WIFI_SECOND_CHAN_NONE);
        Serial.printf("[WiFi] ESP-NOW fallback Ch=%d — must match weight_node Ch (see weight serial)\n",
                      fallbackCh);
        if (!scanCh) {
            Serial.println("[WiFi] Tip: iPhone → Settings → Personal Hotspot → Maximize Compatibility ON");
        }
    }

    cam_ok = initCamera();

    snapshot_buf = (uint8_t*)heap_caps_malloc(
        (size_t)CAM_COLS * CAM_ROWS * 3, MALLOC_CAP_SPIRAM | MALLOC_CAP_8BIT);
    if (!snapshot_buf) Serial.println("[CAM] snapshot_buf alloc FAILED");

    if (esp_now_init() != ESP_OK) { Serial.println("[ESP-NOW] Init FAILED"); return; }
    esp_now_register_send_cb([](const wifi_tx_info_t* info, esp_now_send_status_t st) {
        Serial.printf("[ESP-NOW] %s\n", st == ESP_NOW_SEND_SUCCESS ? "OK" : "FAIL");
    });
    esp_now_peer_info_t peer = {};
    memcpy(peer.peer_addr, weightNodeMAC, 6);
    peer.channel = 0; peer.encrypt = false;
    esp_now_add_peer(&peer);

    Serial.println("[Ready] Waiting for motion...");
}

// ── Loop ──────────────────────────────────────────────────────
void loop() {
    static unsigned long lastWifiRetryMs = 0;
    unsigned long now = millis();
    if (WiFi.status() != WL_CONNECTED && now - lastWifiRetryMs > 30000) {
        lastWifiRetryMs = now;
        Serial.println("[WiFi] Retrying...");
        if (wifiConnectStation(WIFI_SSID, WIFI_PASS, 40)) {
            Serial.printf("[WiFi] OK  Ch=%d\n", WiFi.channel());
        }
    }

    int cur = digitalRead(PIR_PIN);

    if (cur == HIGH && lastPirState == LOW) {
        if (now - lastTriggerTime > PIR_COOLDOWN_MS) {
            lastTriggerTime = now;
            photoCount++;
            Serial.printf("\n[PIR] Motion #%d\n", photoCount);
            if (cam_ok && snapshot_buf && captureAndResize()) {
                float conf = 0;
                uint8_t cat_id = runInference(&conf);
                sendCatID(cat_id, conf);
            }
        } else {
            Serial.println("[PIR] Cooldown");
        }
    }

    lastPirState = cur;
    delay(50);
}

#if !defined(EI_CLASSIFIER_SENSOR) || EI_CLASSIFIER_SENSOR != EI_CLASSIFIER_SENSOR_CAMERA
#error "Invalid model for current sensor — check Edge Impulse model type"
#endif

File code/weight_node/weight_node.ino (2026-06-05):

/*
 * ============================================================
 *  Smart Cat Litter Box — Weight Node  (Fully Wireless)
 *  Board : XIAO ESP32S3
 *  Role  : HX711 weight acquisition + ESP-NOW receive cat ID
 *          + WiFi + MQTT → push data to PC wirelessly
 *
 *  Wiring:
 *    HX711 DT  → GPIO4 (D3)
 *    HX711 SCK → GPIO5 (D4)
 *
 *  MQTT topics published:
 *    litterbox/weight  → "1234.5"       every 500 ms
 *    litterbox/visits  → "{visit JSON}" after each visit
 *    litterbox/status  → "online"       on connect (retained)
 *
 *  MQTT topic subscribed:
 *    litterbox/cmd     ← "tare"         sent from Streamlit
 *
 *  Required libraries (Arduino Library Manager):
 *    - HX711_ADC      (by Olav Kallhovd)
 *    - PubSubClient   (by Nick O'Leary)
 *    - ESP32 core     (WiFi, esp_now — built in)
 * ============================================================
 */

#include <HX711_ADC.h>
#include <EEPROM.h>
#include <WiFi.h>
#include <PubSubClient.h>
#include "esp_now.h"
#include "esp_wifi.h"

#ifndef WIFI_FALLBACK_CHANNEL
#define WIFI_FALLBACK_CHANNEL 6  // match camera_node_3class when both fail WiFi
#endif

// ── ★ Fill in your WiFi credentials and PC's local IP ────────
const char* WIFI_SSID   = "MengqiPhone";
const char* WIFI_PASS   = "gaoxiangshibenben";
const char* MQTT_BROKER = "broker.hivemq.com";  // free public MQTT broker
//   To find your Mac's IP: System Settings → Wi-Fi → Details → IP Address
//   Or run in Terminal:  ipconfig getifaddr en0
const int   MQTT_PORT   = 1883;
// ─────────────────────────────────────────────────────────────

// ── HX711 pins ───────────────────────────────────────────────
const int HX711_dout = 4;
const int HX711_sck  = 5;
HX711_ADC LoadCell(HX711_dout, HX711_sck);
const int CAL_EEPROM_ADDR = 0;

// ── MQTT topics ───────────────────────────────────────────────
#define TOPIC_WEIGHT  "litterbox/weight"
#define TOPIC_VISITS  "litterbox/visits"
#define TOPIC_STATUS  "litterbox/status"
#define TOPIC_CMD     "litterbox/cmd"

// ── ESP-NOW packet struct (must match camera_node) ───────────
typedef struct {
  uint8_t  cat_id;
  float    confidence;
  uint32_t timestamp_ms;
  char     method[8];
} CatIDPacket;

// ── Visit detection thresholds (grams) ───────────────────────
// netWeight = reading - baseline. UI ~700–800 g spikes need enter threshold below that.
// (2000 g was for full litter+猫; too high for current scale readings.)
const float CAT_ENTER_THRESHOLD_G = 400.0;
const float CAT_EXIT_THRESHOLD_G  = 150.0;
const int   STABLE_MS             = 2000;
const int   POST_EXIT_WAIT_MS     = 3000;

// ── Weight-based cat identification ──────────────────────────
const float WESLEY_WEIGHT_G    = 4300.0;
const float PUPU_WEIGHT_G      = 4700.0;
const float WEIGHT_TOLERANCE_G = 300.0;

// ── State machine ─────────────────────────────────────────────
enum VisitState { IDLE, ENTERING, OCCUPIED, LEAVING, POST_EXIT };
VisitState visitState = IDLE;

struct VisitRecord {
  unsigned long entry_ms;
  unsigned long exit_ms;
  float  baseline_before_g;
  float  peak_weight_g;
  float  baseline_after_g;
  uint8_t cat_id;
  float   cam_confidence;
};
VisitRecord curVisit;

// ── Smart baseline — two-phase EMA with stability gating ─────
//
//  Phase 1 (fast):  first BASELINE_FAST_COUNT stable updates
//                   → large blend, baseline converges quickly after power-on
//  Phase 2 (slow):  thereafter → small blend, tracks slow litter drift only
//
//  Gate conditions (both must hold to allow an update):
//    1. std of last BASELINE_WIN readings < BASELINE_STD_G  (signal is stable)
//    2. mean is within BASELINE_NEAR_G of current baseline  (not a cat/hand)
//
const int   BASELINE_WIN        = 10;    // rolling window — larger = smoother
const int   BASELINE_MIN_N      = 4;     // min samples before first update
const int   BASELINE_FAST_COUNT = 30;    // stable updates before switching to slow phase
const float BASELINE_STD_G      = 10.0f; // stability gate (g)
const float BASELINE_NEAR_G     = 200.0f;// proximity gate (g) — cat/hand >> this
const float BASELINE_BLEND_FAST = 0.20f; // fast-phase EMA coefficient
const float BASELINE_BLEND_SLOW = 0.04f; // slow-phase EMA coefficient

float baselineWin[BASELINE_WIN];
int   baselineWinIdx      = 0;
bool  baselineWinFull     = false;
bool  baselineInitialized = false;   // avoids unsafe float == 0 comparison
int   stableUpdateCount   = 0;
float currentBaseline     = 0.0f;

void updateBaseline(float r) {
  baselineWin[baselineWinIdx] = r;
  baselineWinIdx = (baselineWinIdx + 1) % BASELINE_WIN;
  if (baselineWinIdx == 0) baselineWinFull = true;

  int n = baselineWinFull ? BASELINE_WIN : baselineWinIdx;
  if (n < BASELINE_MIN_N) return;

  float sum = 0;
  for (int i = 0; i < n; i++) sum += baselineWin[i];
  float mean = sum / n;

  float var = 0;
  for (int i = 0; i < n; i++) { float d = baselineWin[i] - mean; var += d * d; }
  float sd = sqrtf(var / n);

  if (sd >= BASELINE_STD_G) return;                                    // not stable
  if (baselineInitialized && fabsf(mean - currentBaseline) >= BASELINE_NEAR_G) return; // cat/hand on scale

  if (!baselineInitialized) {
    currentBaseline   = mean;
    baselineInitialized = true;
    stableUpdateCount   = 1;
    Serial.printf("[Baseline] Init = %.1f g\n", currentBaseline);
  } else {
    float blend = (stableUpdateCount < BASELINE_FAST_COUNT)
                  ? BASELINE_BLEND_FAST
                  : BASELINE_BLEND_SLOW;
    currentBaseline = (1.0f - blend) * currentBaseline + blend * mean;
    stableUpdateCount++;
  }
}

// ── ESP-NOW receive buffer ────────────────────────────────────
volatile bool camPktReady = false;
volatile bool camPktNotify = false;
CatIDPacket   latestCamPkt;
unsigned long camPktTime  = 0;
const int     CAM_PKT_VALID_MS = 45000;  // PIR may fire before cat steps on scale

void IRAM_ATTR onDataReceived(const esp_now_recv_info_t* info, const uint8_t* data, int len) {
  if (len == sizeof(CatIDPacket)) {
    memcpy((void*)&latestCamPkt, data, sizeof(CatIDPacket));
    camPktTime  = millis();
    camPktReady = true;
    camPktNotify = true;
  }
}

// ── WiFi + MQTT ───────────────────────────────────────────────
WiFiClient   espClient;
PubSubClient mqtt(espClient);
unsigned long lastWeightMs = 0;
unsigned long lastReconnMs = 0;

static void wifiScanForSsid(const char* ssid) {
  int n = WiFi.scanNetworks(false, true);
  Serial.printf("[WiFi] Scan: %d networks", n);
  bool found = false;
  for (int i = 0; i < n; i++) {
    if (WiFi.SSID(i) == ssid) {
      found = true;
      Serial.printf(" | \"%s\" Ch=%d RSSI=%d", ssid, WiFi.channel(i), WiFi.RSSI(i));
    }
  }
  Serial.println(found ? "" : " | hotspot NOT seen (turn on hotspot, 2.4GHz)");
  WiFi.scanDelete();
}
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

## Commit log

2026-05-09 update UI
    [simple_box_generator(1).3mf]
2026-05-09 update file structure
    [simple_box_generator(1).3mf]
2026-05-27 Update camera node, weight node, UI and add EI model library
2026-05-28 Switch to smaller catIdentifier model (2-class: empty/pupu, Wesley by weight)
2026-05-28 add new smaller model and updated camera code
